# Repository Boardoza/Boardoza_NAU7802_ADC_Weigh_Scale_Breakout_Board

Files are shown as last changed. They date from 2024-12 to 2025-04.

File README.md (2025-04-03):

# Boardoza NAU7802 24-bit Dual-Channel ADC Breakout Board

The **Boardoza NAU7802** is a high-resolution, dual-channel **24-bit analog-to-digital converter breakout board** specifically designed for **weight, pressure, and load cell sensor applications**. It integrates the **NAU7802 ADC** from Nuvoton, known for its **low-noise performance**, **dual differential input channels**, and compact design.

This board is ideal for use in **digital scales**, **pressure transducers**, and any system where **precise analog signal acquisition** is essential. With **I²C communication**, it easily interfaces with microcontrollers and embedded systems, enabling flexible and fast integration.

## [Click here to purchase!](https://www.ozdisan.com/maker-and-iot-products/boardoza/boardoza-modules/BOARDOZA-NAU7802/1206517)

|Front Side|Back Side|
|:---:|:---:|
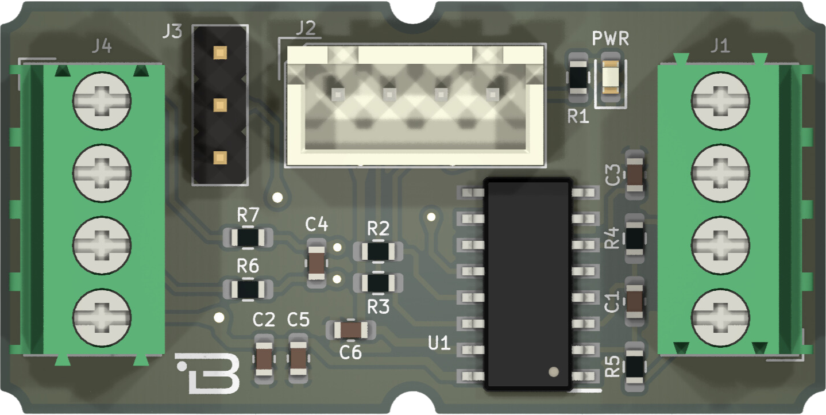
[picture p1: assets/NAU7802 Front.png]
NAU7802 Front
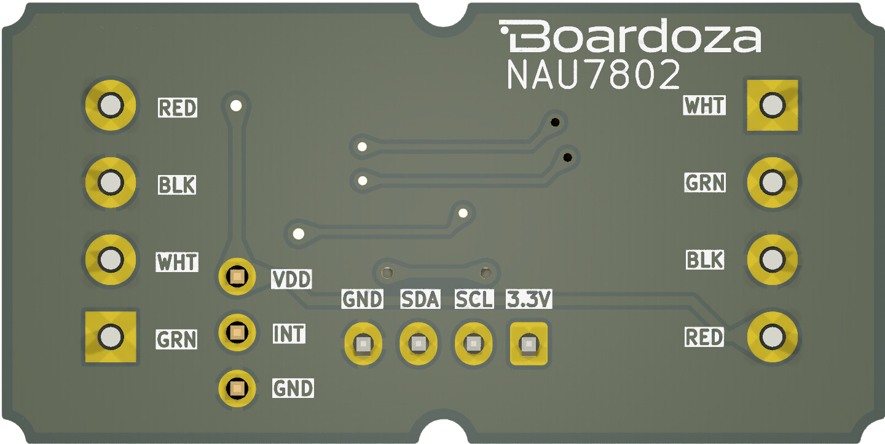
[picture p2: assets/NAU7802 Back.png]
NAU7802 Back
| | |

---

## Key Features

- **24-bit ADC Resolution:** Delivers high-accuracy digital conversion for precise sensor readings.
- **Dual Differential Inputs:** Supports two full differential sensor channels, ideal for load cells.
- **Integrated Low-Noise Amplifier:** Ensures signal integrity and stable readings in noisy environments.
- **Selectable Output Rates:** Allows trade-off between measurement speed and precision.
- **Simple I²C Interface:** Enables easy integration with a wide range of microcontrollers.

---

## Technical Specifications

**Model:** Nuvoton NAU7802  
**Input Voltage:** 2.7V – 5.5V  
**Supply Current:** 2mA  
**Functions:** 24-bit ADC for bridge sensor applications  
**ADC Resolution:** 24-bit  
**Channels:** 2 Differential Input Channels  
**Interface:** I²C  
**Operating Temperature:** -40°C ~ +85°C  
**Board Dimensions:** 20mm x 40mm  

---

## Board Pinout

### ( J1 ) Sensor Channel 1

| Pin Number | Pin Name | Description |
|:---:|---|---|
| 1 | WHT | - Signal |
| 2 | GRN | + Signal |
| 3 | BLK | - Excitation |
| 4 | RED | + Excitation |

### ( J2 ) Power & I²C Communication

| Pin Number | Pin Name | Description |
|:---:|---|---|
| 1 | GND | Ground |
| 2 | SDA | I²C Serial Data |
| 3 | SCL | I²C Serial Clock |
| 4 | 3.3V | Positive Power Supply |

### ( J3 ) Advanced Functionality

| Pin Number | Pin Name | Description |
|:---:|---|---|
| 1 | VDDA | Analog Power Supply |
| 2 | INT | Interrupt Output Pin  |
| 3 | GND | Ground |

### ( J4 ) Sensor Channel 2

| Pin Number | Pin Name | Description |
|:---:|---|---|
| 1 | GRN | + Signal |
| 2 | WHT | - Signal |
| 3 | BLK | - Excitation |
| 4 | RED | + Excitation |

---

## Board Dimensions

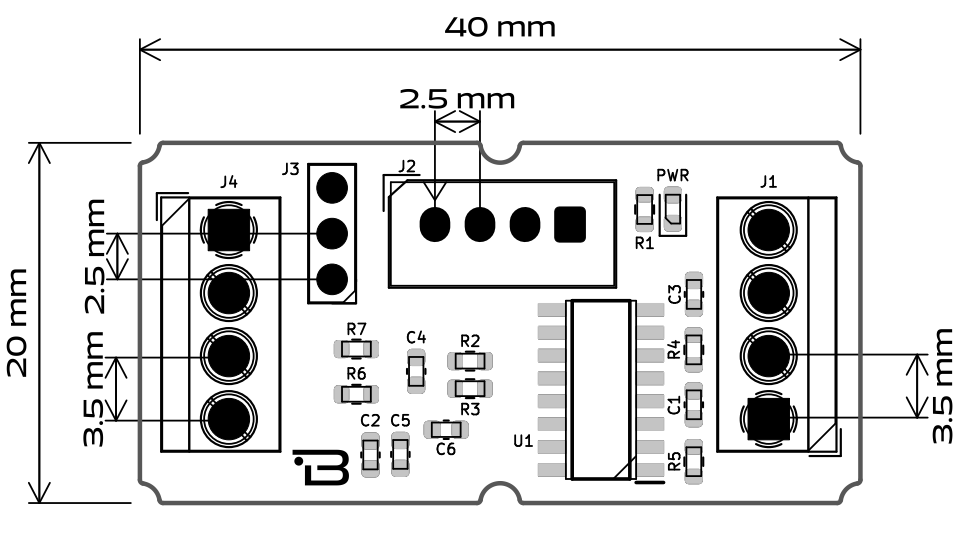
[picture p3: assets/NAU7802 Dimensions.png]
NAU7802 Dimension


---

## Step Files

[Boardoza NAU7802.step](./assets/Boardoza%20NAU7802.step)

---

## Datasheet

[Boardoza NAU7802 Datasheet.pdf](./assets/NAU7802%20Data%20Sheet%20V1.7.pdf)

---

## Version History

- V1.0.0 - Initial Release

---

## Support

- If you have any questions or need support, please contact <support@boardoza.com>

---

## License

Shield: [][cc-by-sa]

This work is licensed under a [Creative Commons Attribution-ShareAlike 4.0 International License][cc-by-sa].

[][cc-by-sa]

[cc-by-sa]: http://creativecommons.org/licenses/by-sa/4.0/
[cc-by-sa-image]: https://licensebuttons.net/l/by-sa/4.0/88x31.png
[cc-by-sa-shield]: https://img.shields.io/badge/License-CC%20BY--SA%204.0-lightgrey.svg

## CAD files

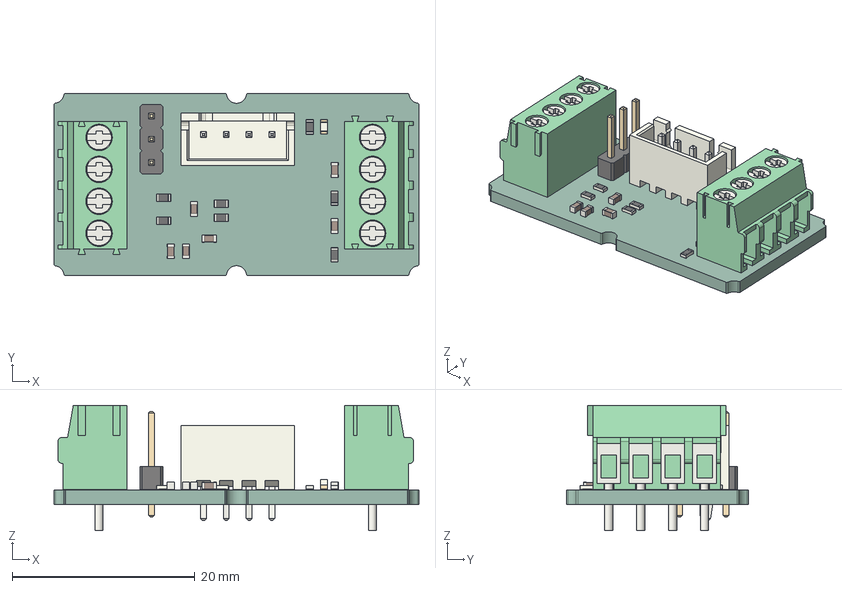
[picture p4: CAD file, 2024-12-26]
assets/Boardoza NAU7802.step
40.0 x 20.0 x 13.7 mm
TerminalBlock_Phoenix_PT_15_4_35_H_1x04_P350mm_Horizontal x 2
C_0603_1608Metric x 6
R_0603_1608Metric x 7
LED_0603_1608Metric
PinHeader_1x03_P254mm_Vertical
JST_B4B_XH_A
_autosave-B-NAU7802-BRK-01MBR-R01_PCB

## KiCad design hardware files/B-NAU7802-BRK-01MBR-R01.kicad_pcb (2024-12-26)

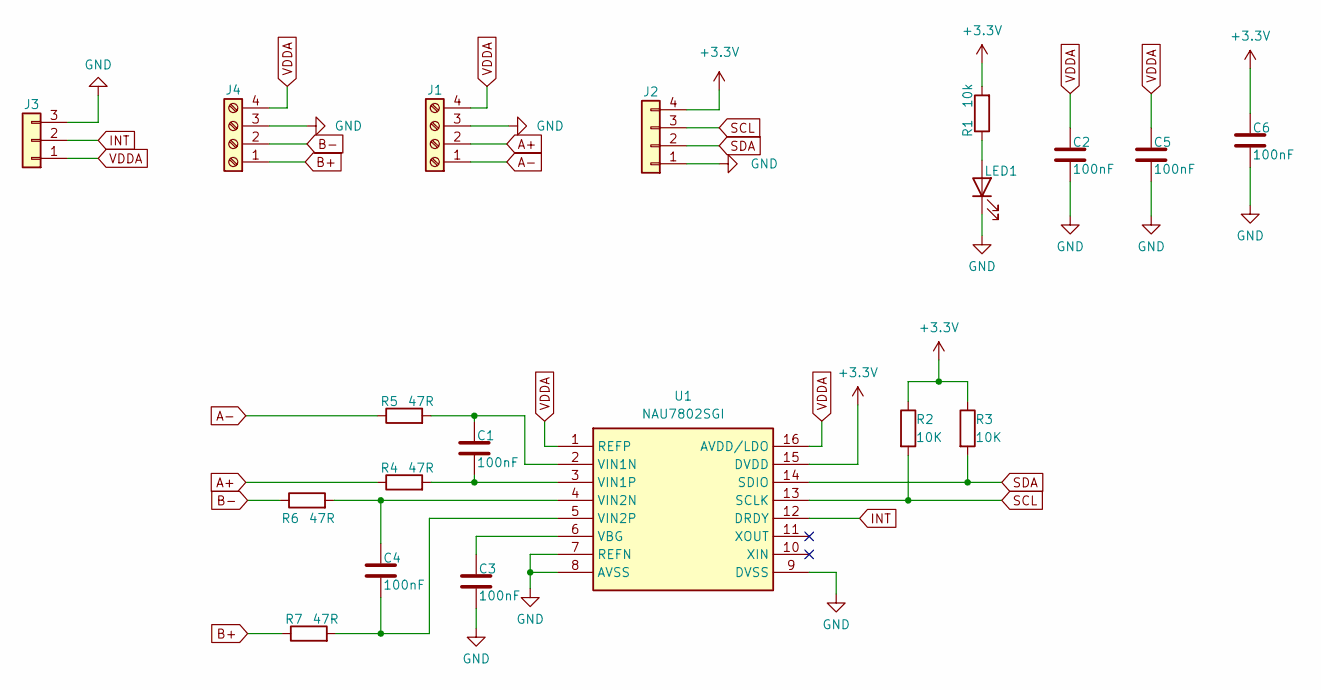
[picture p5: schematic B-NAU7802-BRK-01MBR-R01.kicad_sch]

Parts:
C1, C2, C3, C4, C5, C6: 100nF; C_0603_1608Metric; MPN CL10B104KB8NNNC
J1, J4: Screw_Terminal_01x04; TerminalBlock_MetzConnect_Type059_RT06304HBWC_1x04_P3.50mm_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; MPN DG350-3.5-02P-14-00AH
J2: Conn_01x04; 2317-04S_1x04_P2.50mm_Vertical
J3: Conn_01x03; PinHeader_1x03_P2.54mm_Vertical; MPN L-KLS1-207-1-03-S
LED1: RedPower; LED_0603_1608Metric; MPN 19-213USRC/S259/TR8
R1: 10k; R_0603_1608Metric; MPN 0603SAJ0103T5E
R2, R3: 10K; R_0603_1608Metric; MPN 0603SAJ0103T5E
R4, R5, R6, R7: 47R; R_0603_1608Metric; MPN CQ03SAJ0470T5E
U1: NAU7802SGI; SOIC127P600X175-16N; Manufacturer_Part_Number NAU7802SGI

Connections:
+3.3V: C6.1, J2.4, R1.2, R2.1, R3.1, U1.15 (DVDD)
A+: J1.2, R4.1
A-: J1.1, R5.1
B+: J4.1, R7.1
B-: J4.2, R6.1
GND: C2.2, C3.2, C5.2, C6.2, J1.3, J2.1, J3.3, J4.3, LED1.1 (K), U1.7 (REFN), U1.8 (AVSS), U1.9 (DVSS)
INT: J3.2, U1.12 (DRDY)
unnamed: LED1.2 (A), R1.1
unnamed: C3.1, U1.6 (VBG)
unnamed: C1.1, R5.2, U1.2 (VIN1N)
unnamed: C1.2, R4.2, U1.3 (VIN1P)
unnamed: C4.1, R6.2, U1.4 (VIN2N)
unnamed: C4.2, R7.2, U1.5 (VIN2P)
SCL: J2.3, R2.2, U1.13 (SCLK)
SDA: J2.2, R3.2, U1.14 (SDIO)
VDDA: C2.1, C5.1, J1.4, J3.1, J4.4, U1.1 (REFP), U1.16 (AVDD/LDO)

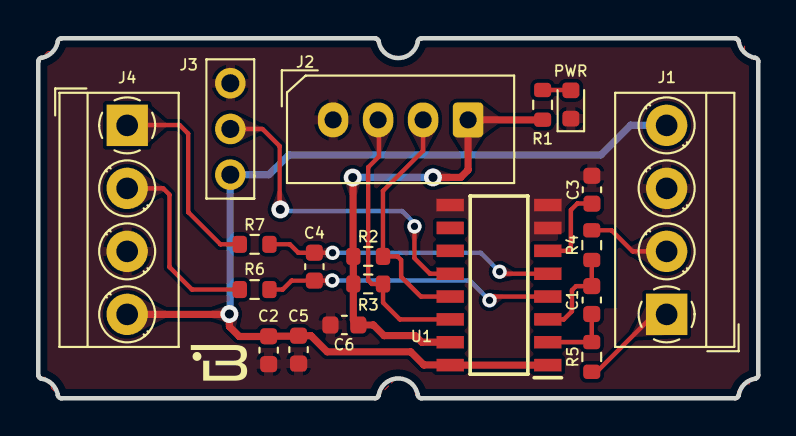
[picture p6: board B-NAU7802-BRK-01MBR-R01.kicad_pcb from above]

Board: 2 copper layers, 40.0 x 20.0 mm, 19 parts (0 on the bottom side), 16 nets.

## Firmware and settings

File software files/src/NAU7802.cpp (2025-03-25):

#include <NAU7802.h>

int32_t offSetValue = 0;

NAU7802::NAU7802() {}

/**
 * @brief Initializes the NAU7802 module.
 * 
 * This function initializes the NAU7802 module by beginning communication with Wire, setting the sample rate to 10SPS,
 * setting the gain to 128, setting the LDO voltage, configuring the ADC and power registers, and powering up the module.
 * 
 * @return True if the initialization is successful, otherwise false.
 */
bool NAU7802::begin() {

    Wire.begin();
    setSampleRate(RATE_10SPS);
    setGain(GAIN_128);
    setLdoVoltage(NAU7802_3v0);
    setBit(0x15, 4); //ADC register
    setBit(0x15, 5); //ADC register
    //setBit(0x1B, 6); //PGA register
    setBit(0x1C, 7); //PWR register

    powerUp();

    return true;
}

/**
 * @brief Checks if the NAU7802 module is available for communication.
 * 
 * This function checks if the NAU7802 module is available for communication by beginning a transmission with the default address
 * and checking if the end of the transmission is successful.
 * 
 * @return True if the module is available for communication, otherwise false.
 */
bool NAU7802::isAvailable() {
    Wire.beginTransmission(NAU7802_DEFAULT_ADDR);
    return Wire.endTransmission() == 0;
}

/**
 * @brief Resets the NAU7802 module.
 * 
 * This function resets the NAU7802 module by setting the reset bit in the power-up control register, delaying for 10 milliseconds,
 * and then clearing the reset bit.
 */
void NAU7802::reset() {
    setBit(NAU7802_PU_CTRL, PU_CTRL_RR);
    delay(10);
    return (clearBit(NAU7802_PU_CTRL, PU_CTRL_RR));
}

/**
 * @brief Powers up the NAU7802 module.
 * 
 * This function powers up the NAU7802 module by setting the power-up and power-up analog bits in the power-up control register,
 * waiting for the power-up ready bit to be set, setting the chip select bit, and returning true if the module is successfully powered up.
 * 
 * @return True if the module is successfully powered up, false if the operation times out.
 */
bool NAU7802::powerUp() {
    setBit(NAU7802_PU_CTRL, PU_CTRL_PUD);
    setBit(NAU7802_PU_CTRL, PU_CTRL_PUA);

    uint8_t counter = 0;
    while(1) {
        if(readBit(NAU7802_PU_CTRL, PU_CTRL_PUR)) {
        break;
        }
        delay(10);
        if(counter++ > 100) {
        return false;
        }
    }
    setBit(NAU7802_PU_CTRL, PU_CTRL_CS);

    return true;
}

/**
 * @brief Powers down the NAU7802 module.
 * 
 * This function powers down the NAU7802 module by clearing the power-up and power-up analog bits in the power-up control register.
 * 
 * @return True if the module is successfully powered down.
 */
bool NAU7802::powerDown() {
    clearBit(NAU7802_PU_CTRL, PU_CTRL_PUD);
    clearBit(NAU7802_PU_CTRL, PU_CTRL_PUA);
}

/**
 * @brief Performs calibration on the NAU7802 module.
 * 
 * This function initiates the calibration process by setting the calibration start bit in the control register,
 * waits for the calibration to finish, and checks for any calibration errors.
 * 
 * @return True if calibration is successful and there are no calibration errors, false otherwise.
 */
bool NAU7802::calibrate() {
    setBit(NAU7802_CTRL2, CTRL2_CALS); // Begin calibration
    readUntilFalse(NAU7802_CTRL2, CTRL2_CALS); // Wait for calibration to finish
    return !readBit(NAU7802_CTRL2, CTRL2_CAL_ERR); // Check for calibration error
}

/**
 * @brief Reads the ADC value from the NAU7802 module.
 * 
 * This function waits until the conversion is ready by checking the conversion ready bit in the power-up control register,
 * reads the ADC value from the specified register, and returns the ADC value as a signed 32-bit integer.
 * 
 * @return The ADC value read from the NAU7802 module as a signed 32-bit integer.
 */
int32_t NAU7802::readADCValue() {
    readUntilTrue(NAU7802_PU_CTRL, PU_CTRL_CR);
    uint32_t adcValue = read24(NAU7802_ADCO_B2);
    return (int32_t)adcValue;
}

/**
 * @brief Selects the channel on the NAU7802 module.
 * 
 * This function selects the specified channel on the NAU7802 module by setting or clearing the channel select bit in the control register.
 * It then performs calibration to ensure accurate readings for the selected channel.
 * 
 * @param channel The channel to be selected (CHANNEL1 or CHANNEL2).
 */
void NAU7802::channelSelect(Channels channel) {
    if(channel == CHANNEL1) {
        clearBit(NAU7802_CTRL2, 7); // Channel 1 selected
    }else if(channel == CHANNEL2) {
        setBit(NAU7802_CTRL2, 7); // Channel 2 selected
    }
    calibrate();
}

/**
 * @brief Reads the voltage value from the NAU7802 module.
 * 
 * This function reads the raw ADC value from the module, and then calculates and returns the voltage value represented by the ADC reading.
 * The reference voltage, gain setting, and full scale range of the ADC are used in the calculation.
 * 
 * @return The voltage value read from the NAU7802 module in float format.
 */
float NAU7802::readVoltage() {
    // Read the raw ADC value
    int32_t rawADCValue = readADCValue();

    // The reference voltage used for the NAU7802
    float referenceVoltage = 3.3;

    // The gain setting used for the NAU7802
    float gain = 128.0;

    // The full scale range of the ADC
    int32_t fullScaleRange = 8388608; // 2^23

    // Calculate the voltage
    float voltage = (rawADCValue * referenceVoltage) / (gain * fullScaleRange);
    
    return voltage;
}

/**
 * @brief Sets the calibration mode for the NAU7802 module.
 * 
 * This function sets the calibration start bit, calibration mode bit, and additional calibration mode bit in the control register
 * to enable calibration mode for the NAU7802 module.
 */
void NAU7802::setCalibration() {
    setBit(NAU7802_CTRL2, CTRL2_CALS);
    setBit(NAU7802_CTRL2, CTRL2_CALMOD);
    setBit(NAU7802_CTRL2, CTRL2_CALMOD + 1);
}

/**
 * @brief Performs tare operation on the NAU7802 module.
 * 
 * This function reads the ADC value multiple times with a delay interval, calculates the average, and sets the offset value
 * to compensate for any drift or initial measurement bias. The calculated offset value is stored in the 'offSetValue' variable.
 * 
 * @param times The number of times to read ADC value for tare calculation.
 */
void NAU7802::tare(byte times) {
    long sum = 0;

    for(byte i = 0; i < times; ++i) {
        sum += readADCValue();
        delay(100);
    }
    offSetValue = (sum / times);
    Serial.print(offSetValue);
        Serial.print("  ");
    Serial.print(sum);
        Serial.println("  ");
}
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

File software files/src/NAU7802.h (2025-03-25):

#ifndef NAU7802_h
#define NAU7802_h

#include <Arduino.h>
#include <Wire.h>

#define NAU7802_DEFAULT_ADDR 0x2A
#define NAU7802_PU_CTRL 0x00
#define NAU7802_CTRL1 0x01
#define NAU7802_CTRL2 0x02
#define NAU7802_ADCO_B2 0x12
#define NAU7802_ADC 0x15
#define NAU7802_PGA 0x1B
#define NAU7802_POWER 0x1C
#define NAU7802_REVISION_ID 0x1F

typedef enum {
    NAU7802_4v5 = 0b000,
    NAU7802_4v2 = 0b001,
    NAU7802_3v9 = 0b010,
    NAU7802_3v6 = 0b011,
    NAU7802_3v3 = 0b100,
    NAU7802_3v0 = 0b101,
    NAU7802_2v7 = 0b110,
    NAU7802_2v4 = 0b111,
} LdoVoltages;

typedef enum  {
    GAIN_1 = 0b000,
    GAIN_2 = 0b001,
    GAIN_4 = 0b010,
    GAIN_8 = 0b011,
    GAIN_16 = 0b100,
    GAIN_32 = 0b101,
    GAIN_64 = 0b110,
    GAIN_128 = 0b111,
} Gain;

typedef enum {
    RATE_10SPS = 0b000,
    RATE_20SPS = 0b001,
    RATE_40SPS = 0b010,
    RATE_80SPS = 0b011,
    RATE_320SPS = 0b111,
} SampleRate;

typedef enum {
    CHANNEL1 = 0,
    CHANNEL2 = 1,
} Channels;

// PU_CTRL register
typedef enum {
    PU_CTRL_RR = 0,
    PU_CTRL_PUD = 1,
    PU_CTRL_PUA = 2,
    PU_CTRL_PUR = 3,
    PU_CTRL_CS = 4,
    PU_CTRL_CR = 5,
    PU_CTRL_OSCS = 6,
    PU_CTRL_AVDDS = 7,
} PU_CTRL_Bits;

// CTRL1 registers
typedef enum {
    CTRL1_GAIN = 2,
    CTRL1_VLDO = 5,
    CTRL1_DRDY_SEL = 6,
    CTR1_CRP = 7,
} CTRL1_Bits;

// CTRL2 Registers
typedef enum {
    CTRL2_CALMOD = 0,
    CTRL2_CALS = 2,
    CTRL2_CAL_ERR = 3,
    CTRL2_CRS = 4,
    CTRL2_CHS = 7,
} CTRL2_Bits;

// PGA registers
typedef enum {
    PGA_CHP_DIS = 0,
    PGA_INV = 3,
    PGA_BYPASS_ENABLE = 4,
    PGA_OUT_BUF_EN = 5,
    PGA_LDO_MODE = 6,
    PGA_RD_OTP_SEL = 7,
} PGA_Bits;

// Calibration mode
typedef enum {
    CALMODE_INTERNAL = 0,
    CALMODE_OFFSET = 2,
    CALMODE_GAIN = 3,
} CalibrationMode;

class NAU7802 {
  public:
    NAU7802();
    bool begin();
    void reset();
    bool isAvailable();
    bool powerUp();
    bool powerDown();
    bool calibrate();
    int32_t readADCValue();
    void channelSelect(Channels channel);
    float readVoltage();
    float readWeight(float calibrationFactor);
    void setCalibration();
    void tare(byte times);
    int32_t setOffset(int32_t tempADCValue);
    void setGain(Gain gain);
    void setSampleRate(SampleRate rate);
    void setChannel(Channels channel);
    void setLdoVoltage(LdoVoltages voltage);
    void calibTest();
  private:
    uint8_t readRegister(uint8_t reg);
    void writeRegister(uint8_t reg, uint8_t value);
    uint32_t read24(uint8_t reg);
    void setBit(uint8_t reg, uint8_t bit);
    void clearBit(uint8_t reg, uint8_t bit);
    bool readBit(uint8_t reg, uint8_t bit);
    void readUntilTrue(uint8_t reg, uint8_t bit);
    void readUntilFalse(uint8_t reg, uint8_t bit);
    float _calibrationFactor;
    int32_t _offset;
};

#endif

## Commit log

2024-12-26 Initial release for NAU7802 Breakout Board
    [B-NAU7802-BRK-01MBR-R01-B_Cu.gbl, B-NAU7802-BRK-01MBR-R01-B_Mask.gbs, B-NAU7802-BRK-01MBR-R01-B_Paste.gbp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]
2025-01-28 Remove Gerber files.
    [B-NAU7802-BRK-01MBR-R01-B_Cu.gbl, B-NAU7802-BRK-01MBR-R01-B_Mask.gbs, B-NAU7802-BRK-01MBR-R01-B_Paste.gbp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]
2025-04-03 Update README.md to enhance product description and add key features for NAU7802 breakout board
